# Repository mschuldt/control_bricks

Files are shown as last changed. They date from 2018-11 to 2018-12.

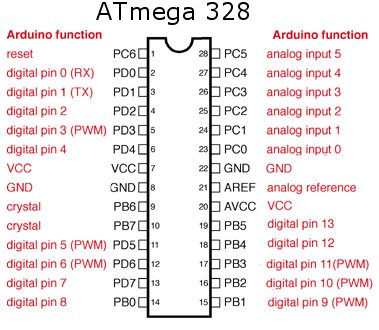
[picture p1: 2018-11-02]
datasheets/atmega328-arduino-pinout.jpg

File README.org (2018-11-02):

Control Bricks

A collection of composable PCBs for building simple automation solutions.

Bricks are connected in sequence, each performing a simple function before
passing control to the next brick. 
Bricks can have inputs for sensors and outputs for actuators.

The goal is to create reliable and maintainable solutions 
without any custom application specific software. 
The PCBs provide buttons and indicators for the control interface. 
Each output has buttons for manual activation for testing and debugging.

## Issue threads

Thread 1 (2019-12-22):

SN74LV8153 is unused

Ryder17z, 2019-12-22:
You have the PDF but the device hasn't been implemented. That's unfortunate.

mschuldt, 2019-12-22:
yup, ended up not needing it. Why is that unfortunate?

Ryder17z, 2019-12-26:
Because I got a bunch of these chips and I want ideas for what to do with them and how.

mschuldt, 2019-12-26:
This project won't help you much in that case

Ryder17z, 2019-12-26:
not with that particular chip, no but otherwise it looks interesting.

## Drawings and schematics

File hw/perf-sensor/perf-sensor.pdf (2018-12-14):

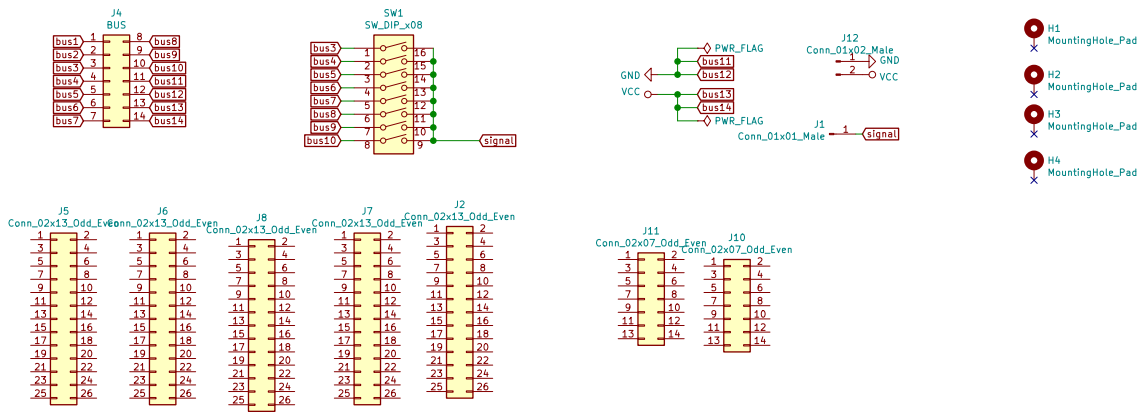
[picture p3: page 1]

File: perf-sensor.sch Sheet: /
Id: 1/1 Title:

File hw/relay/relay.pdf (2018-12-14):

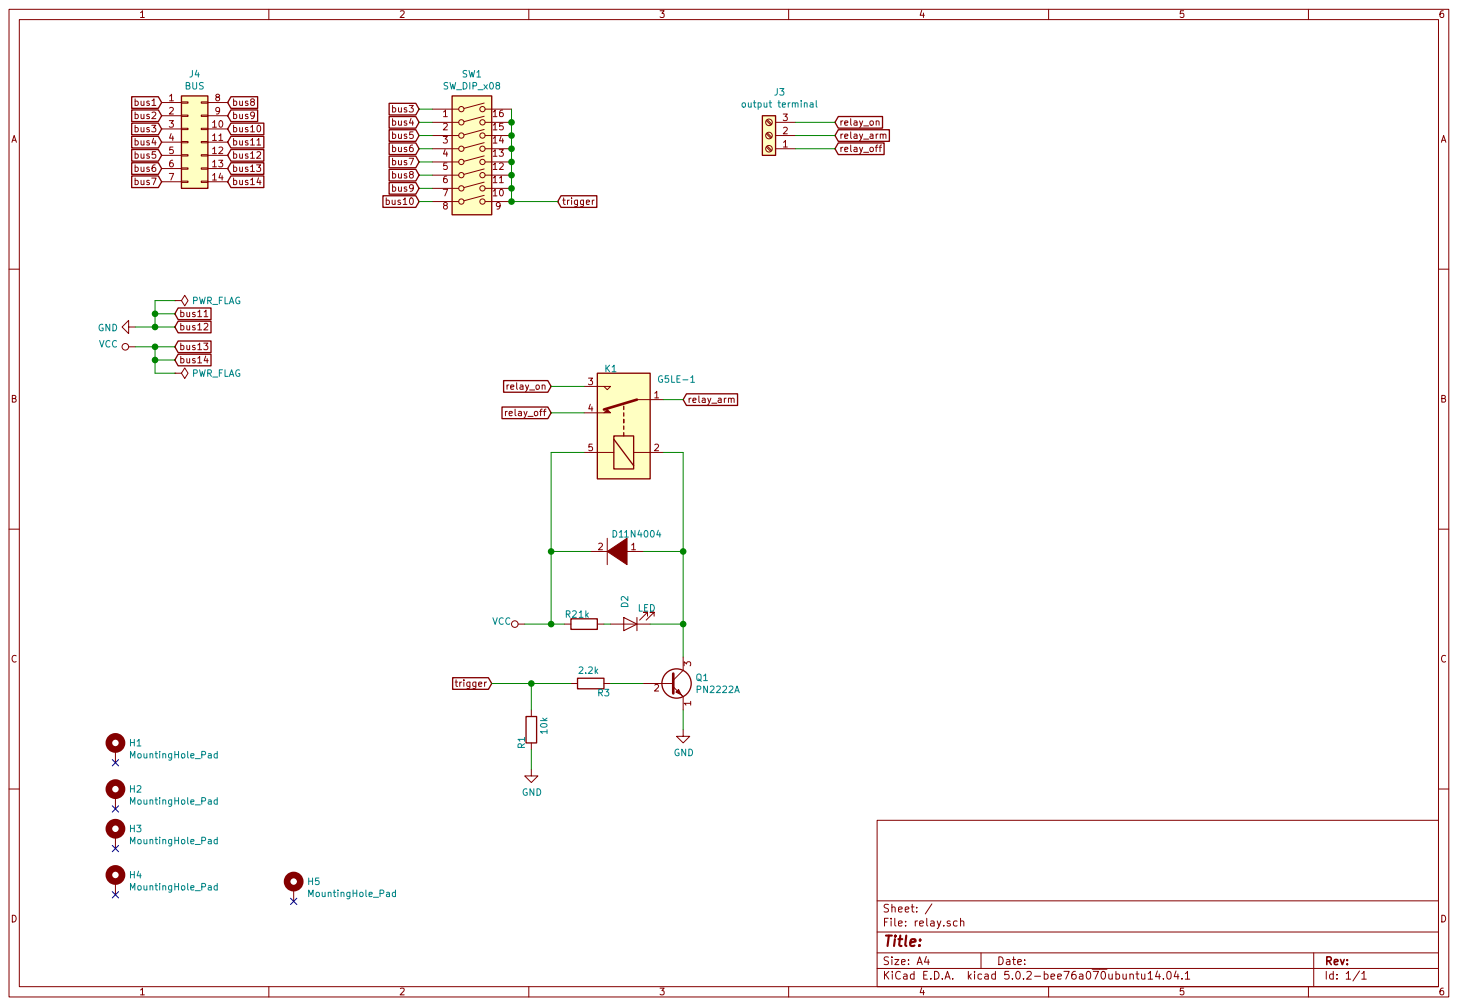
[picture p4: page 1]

File: relay.sch Sheet: /
Id: 1/1 Title:

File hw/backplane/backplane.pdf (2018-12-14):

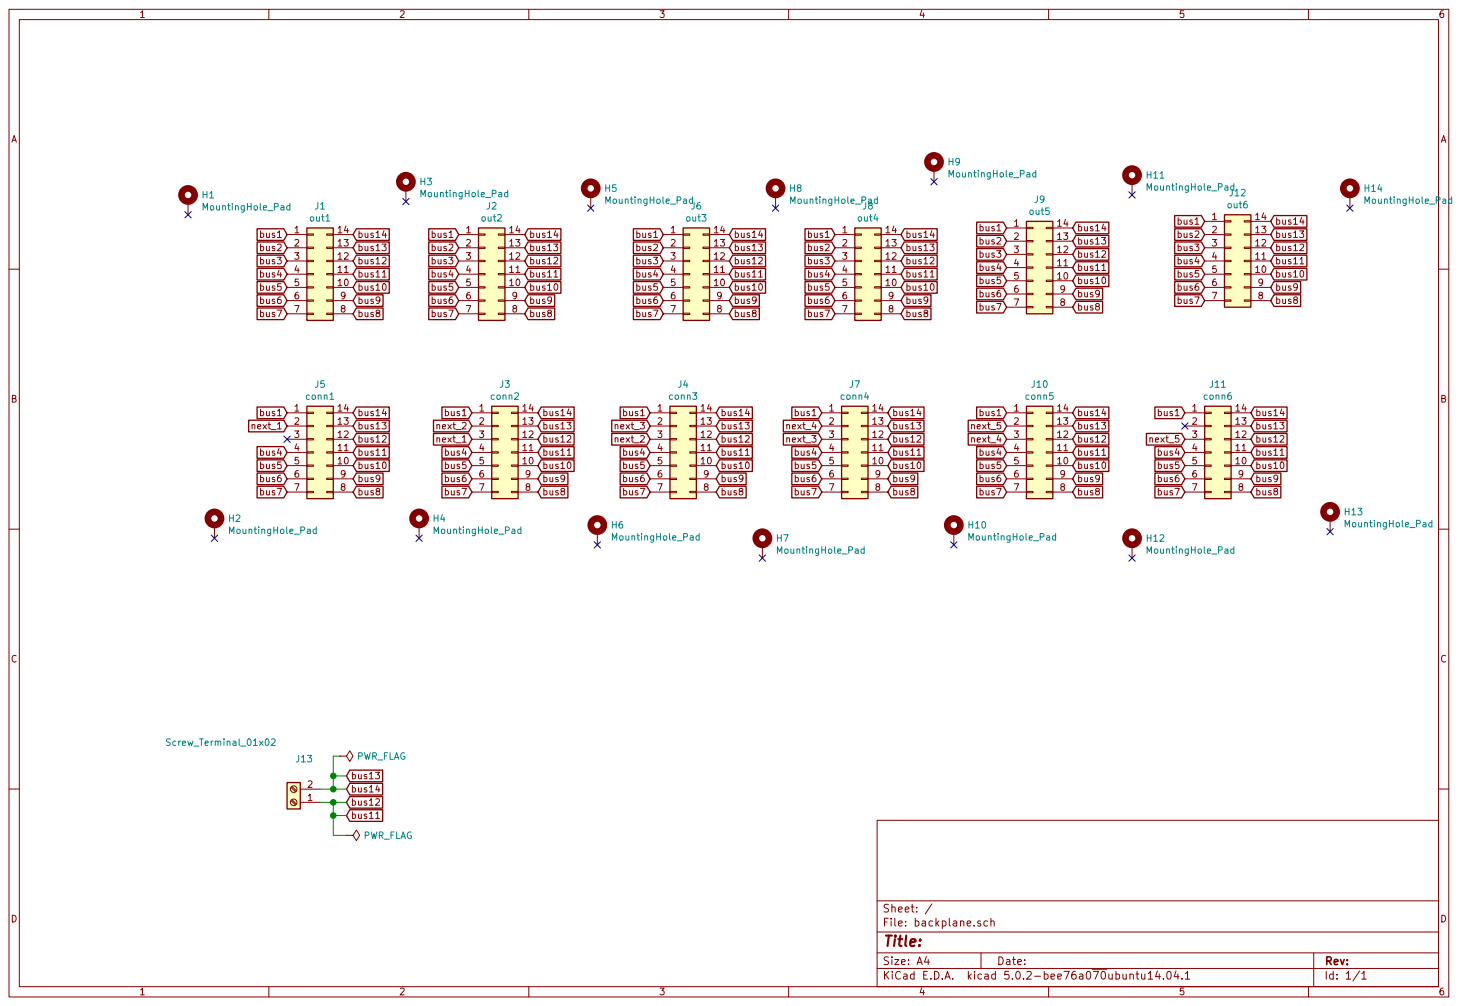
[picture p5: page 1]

File: backplane.sch Sheet: /
Id: 1/1 Title:

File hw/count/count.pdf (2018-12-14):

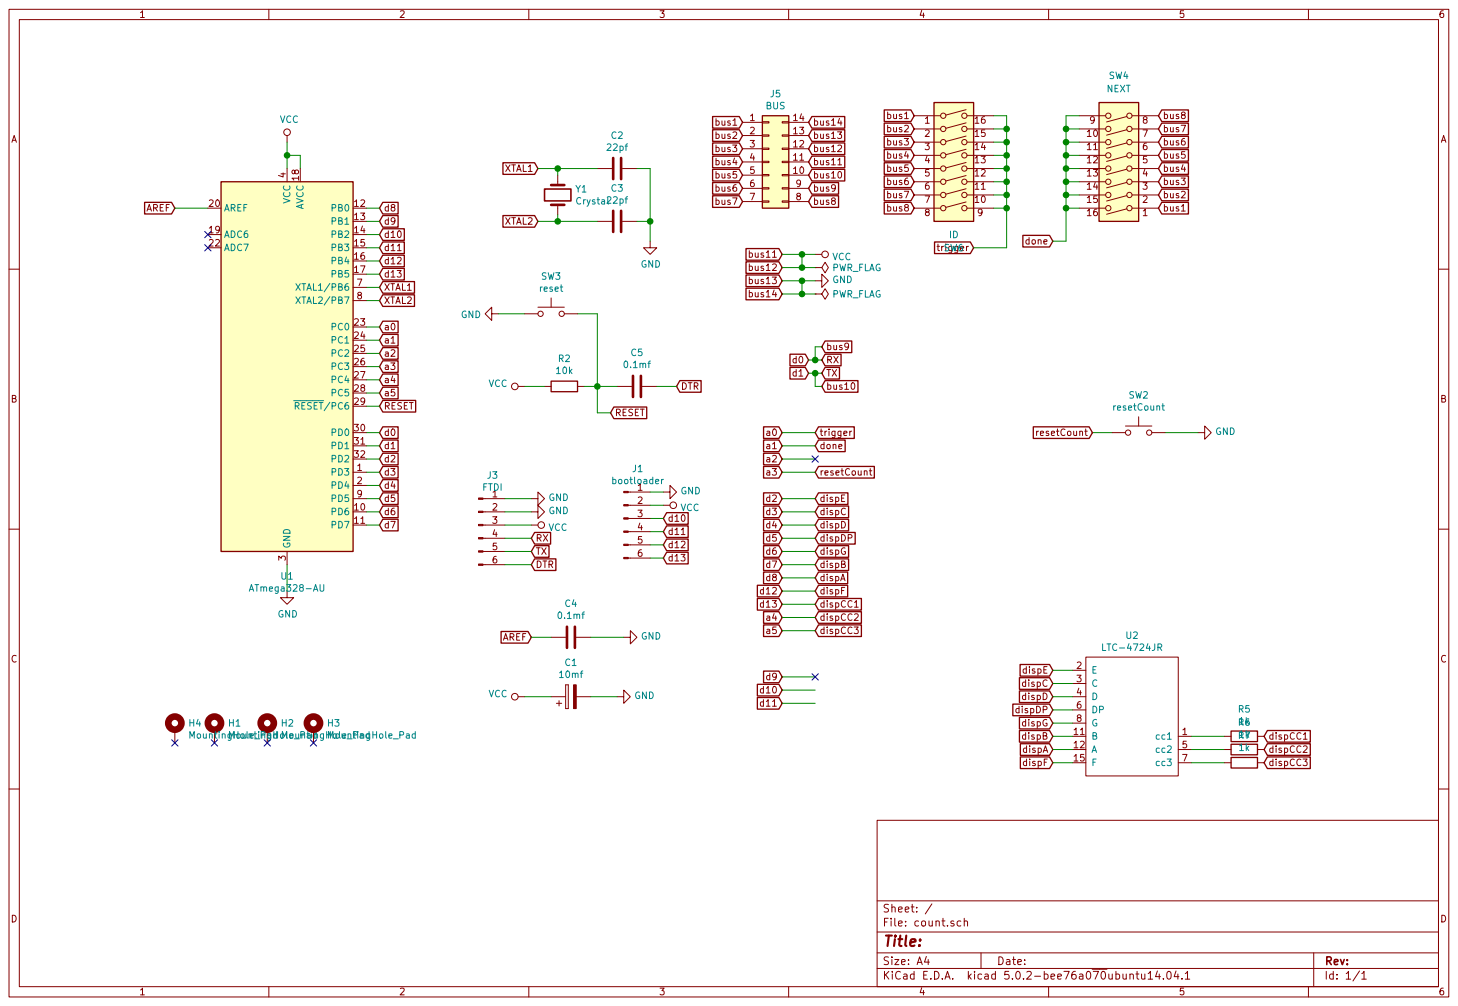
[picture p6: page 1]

Id: 1/1 Title: File: count.sch Sheet: /

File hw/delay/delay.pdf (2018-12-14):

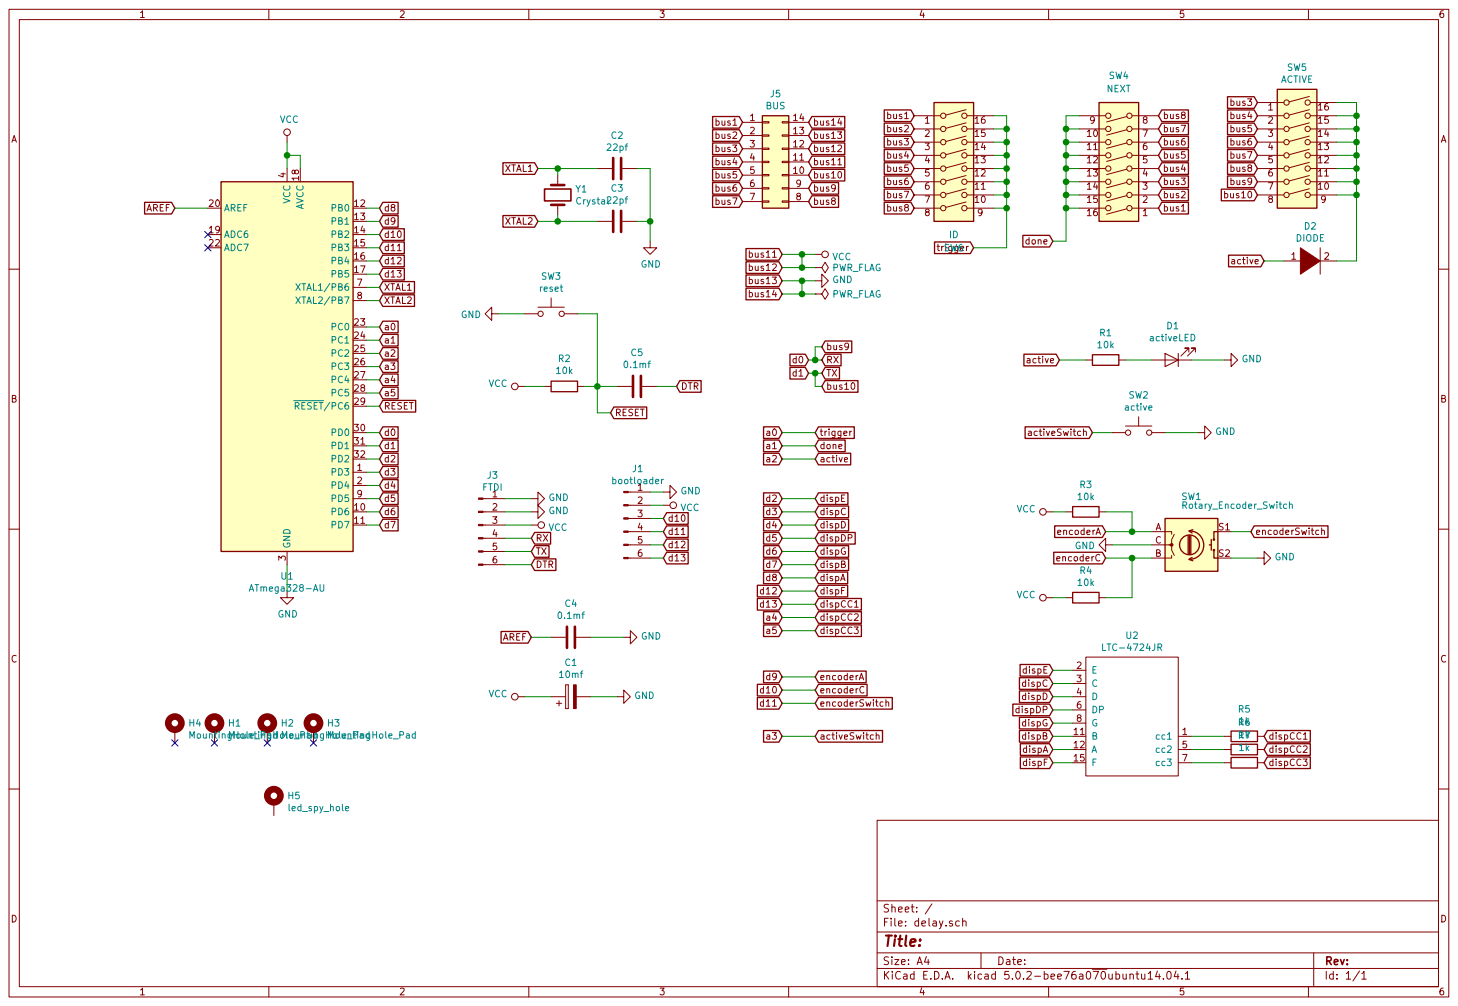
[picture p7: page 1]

File: delay.sch Sheet: /
Id: 1/1 Title:

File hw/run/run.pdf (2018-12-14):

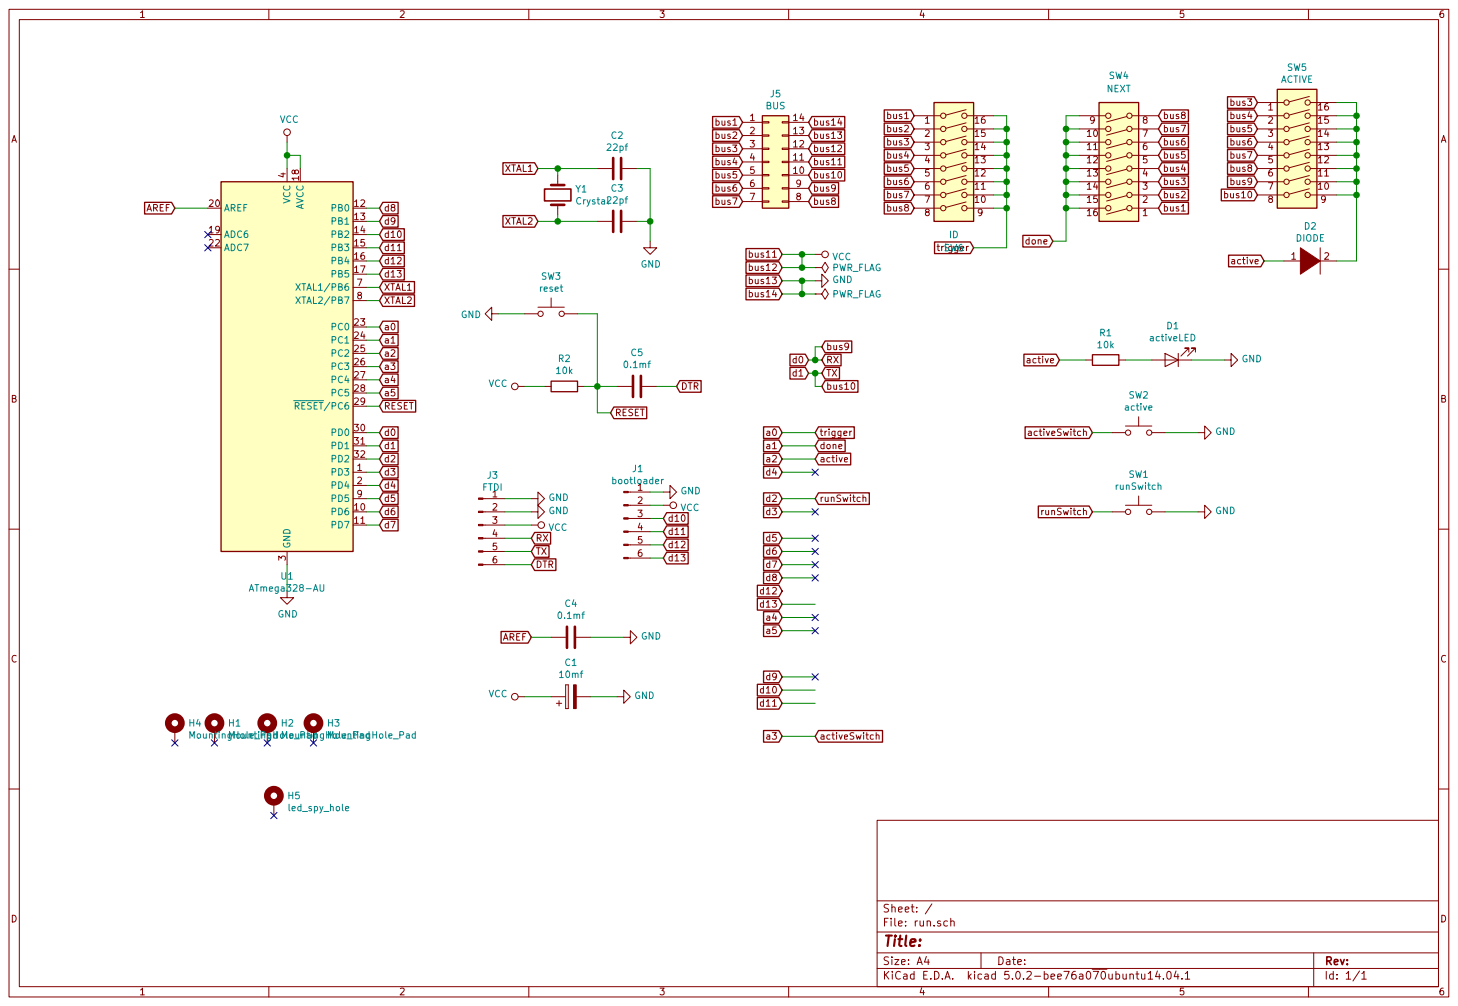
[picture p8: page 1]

Id: 1/1 Title: File: run.sch Sheet: /

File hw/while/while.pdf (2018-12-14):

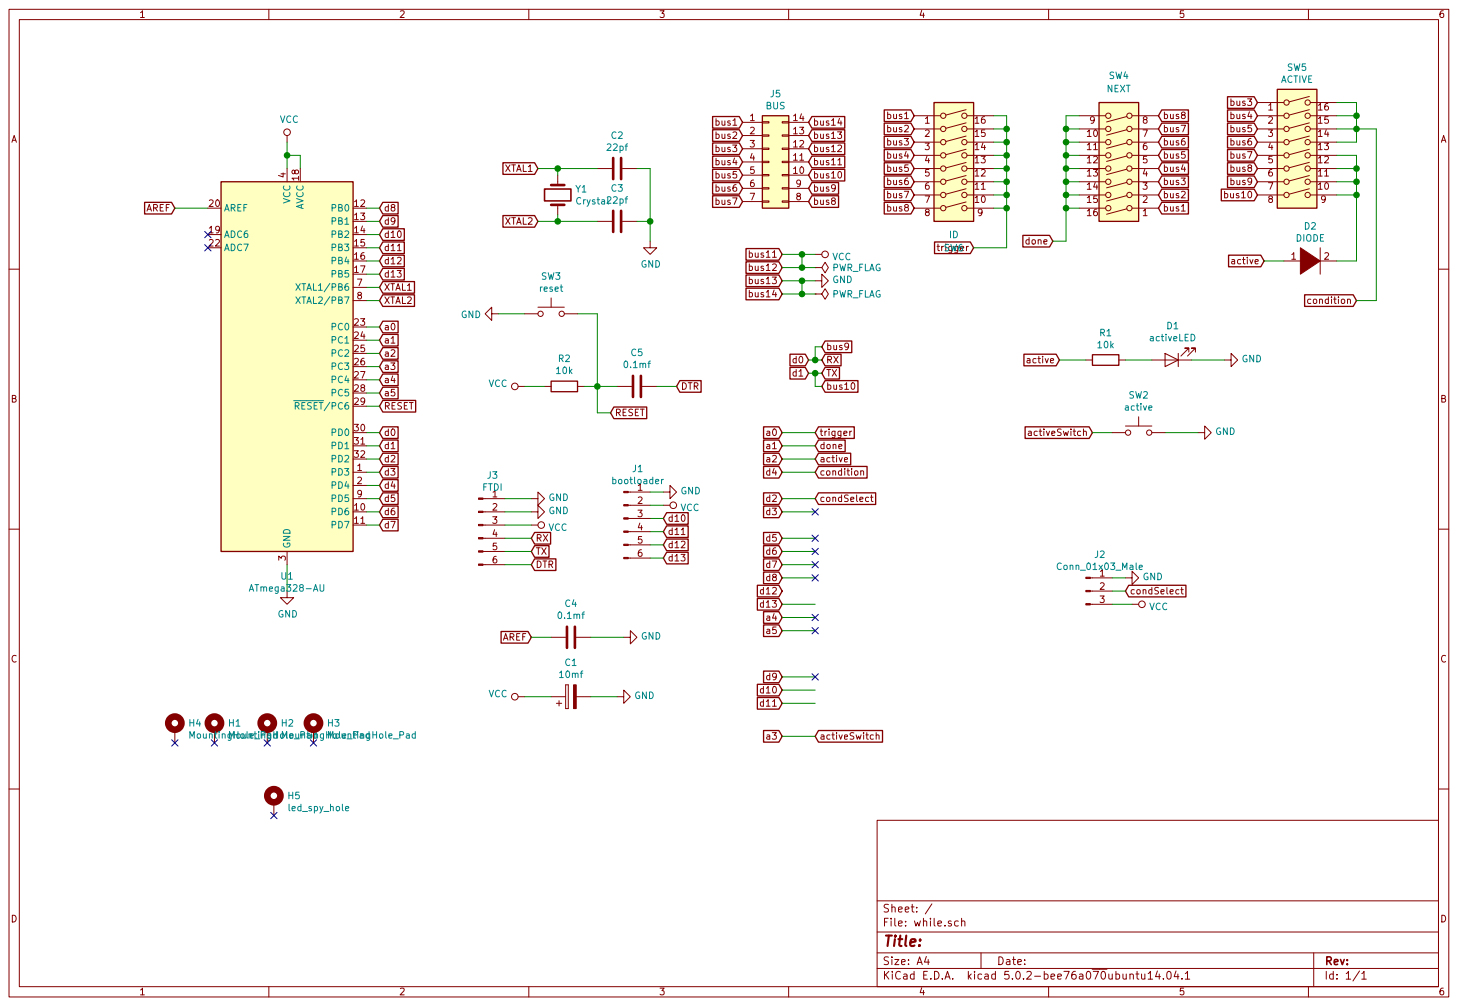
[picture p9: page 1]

Id: 1/1 Title: File: while.sch Sheet: /

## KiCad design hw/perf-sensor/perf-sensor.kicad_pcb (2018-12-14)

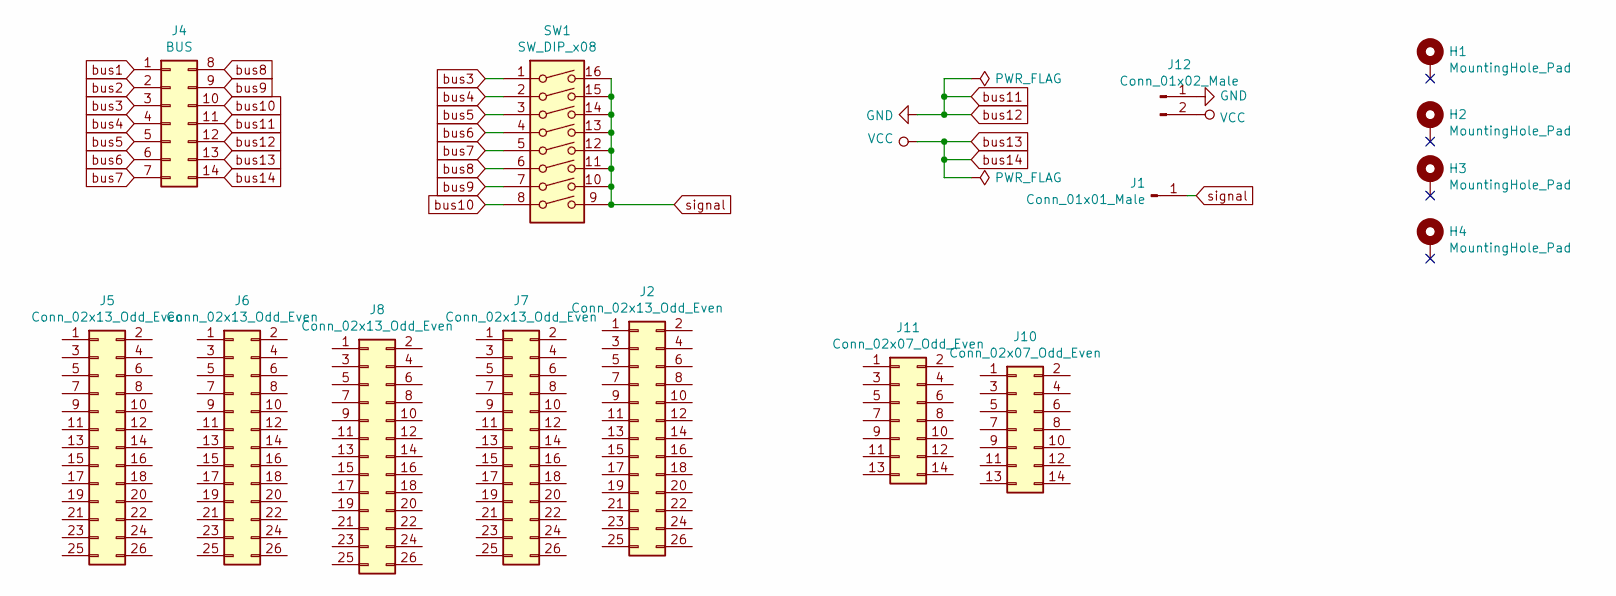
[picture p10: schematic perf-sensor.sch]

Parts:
H1, H2, H3, H4: MountingHole_Pad; MountingHole_3.2mm_M3
J1: Conn_01x01_Male; PinHeader_1x01_P2.54mm_Vertical
J2, J5, J6, J7, J8: Conn_02x13_Odd_Even; PinHeader_2x13_P2.54mm_Vertical
J4: BUS; PinHeader_2x07_P2.54mm_Vertical
J10, J11: Conn_02x07_Odd_Even; PinHeader_2x07_P2.54mm_Vertical
J12: Conn_01x02_Male; PinHeader_1x02_P2.54mm_Vertical
SW1: SW_DIP_x08; DIP-16_W7.62mm_SMDSocket_SmallPads

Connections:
bus1: J4.1
bus2: J4.2
bus3: J4.3, SW1.1
bus4: J4.4, SW1.2
bus5: J4.5, SW1.3
bus6: J4.6, SW1.4
bus7: J4.7, SW1.5
bus8: J4.8, SW1.6
bus9: J4.9, SW1.7
bus10: J4.10, SW1.8
bus11: J4.11, J4.12, J12.1
bus13: J4.13, J4.14, J12.2
signal: J1.1, SW1.9, SW1.10, SW1.11, SW1.12, SW1.13, SW1.14, SW1.15, SW1.16

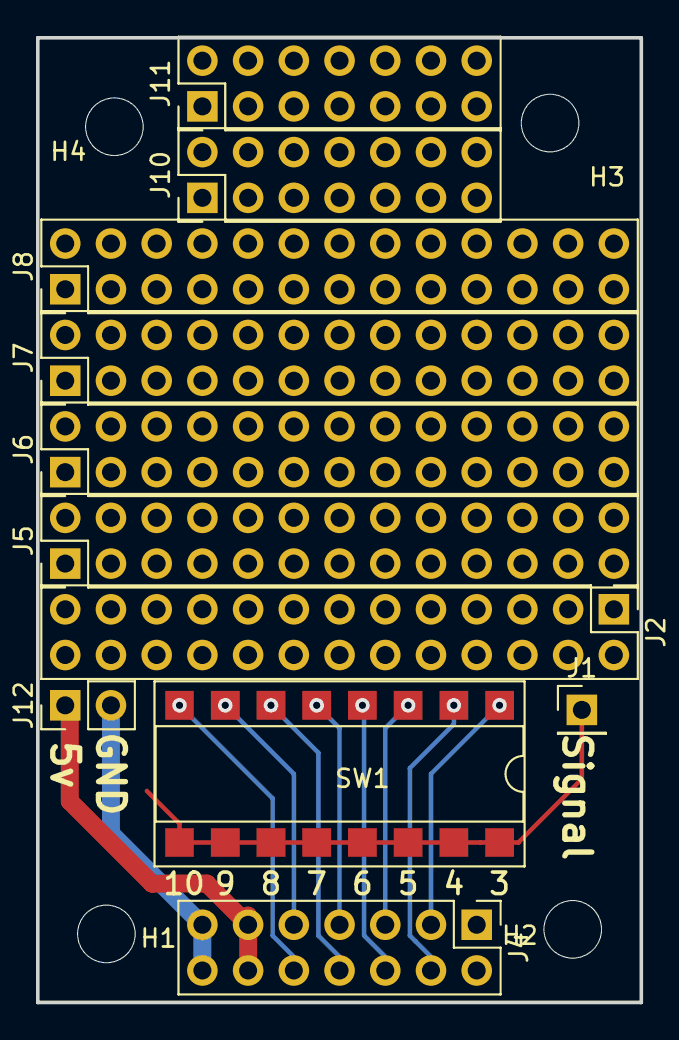
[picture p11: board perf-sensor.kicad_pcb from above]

Board: 2 copper layers, 33.5 x 53.6 mm, 15 parts (0 on the bottom side), 11 nets.

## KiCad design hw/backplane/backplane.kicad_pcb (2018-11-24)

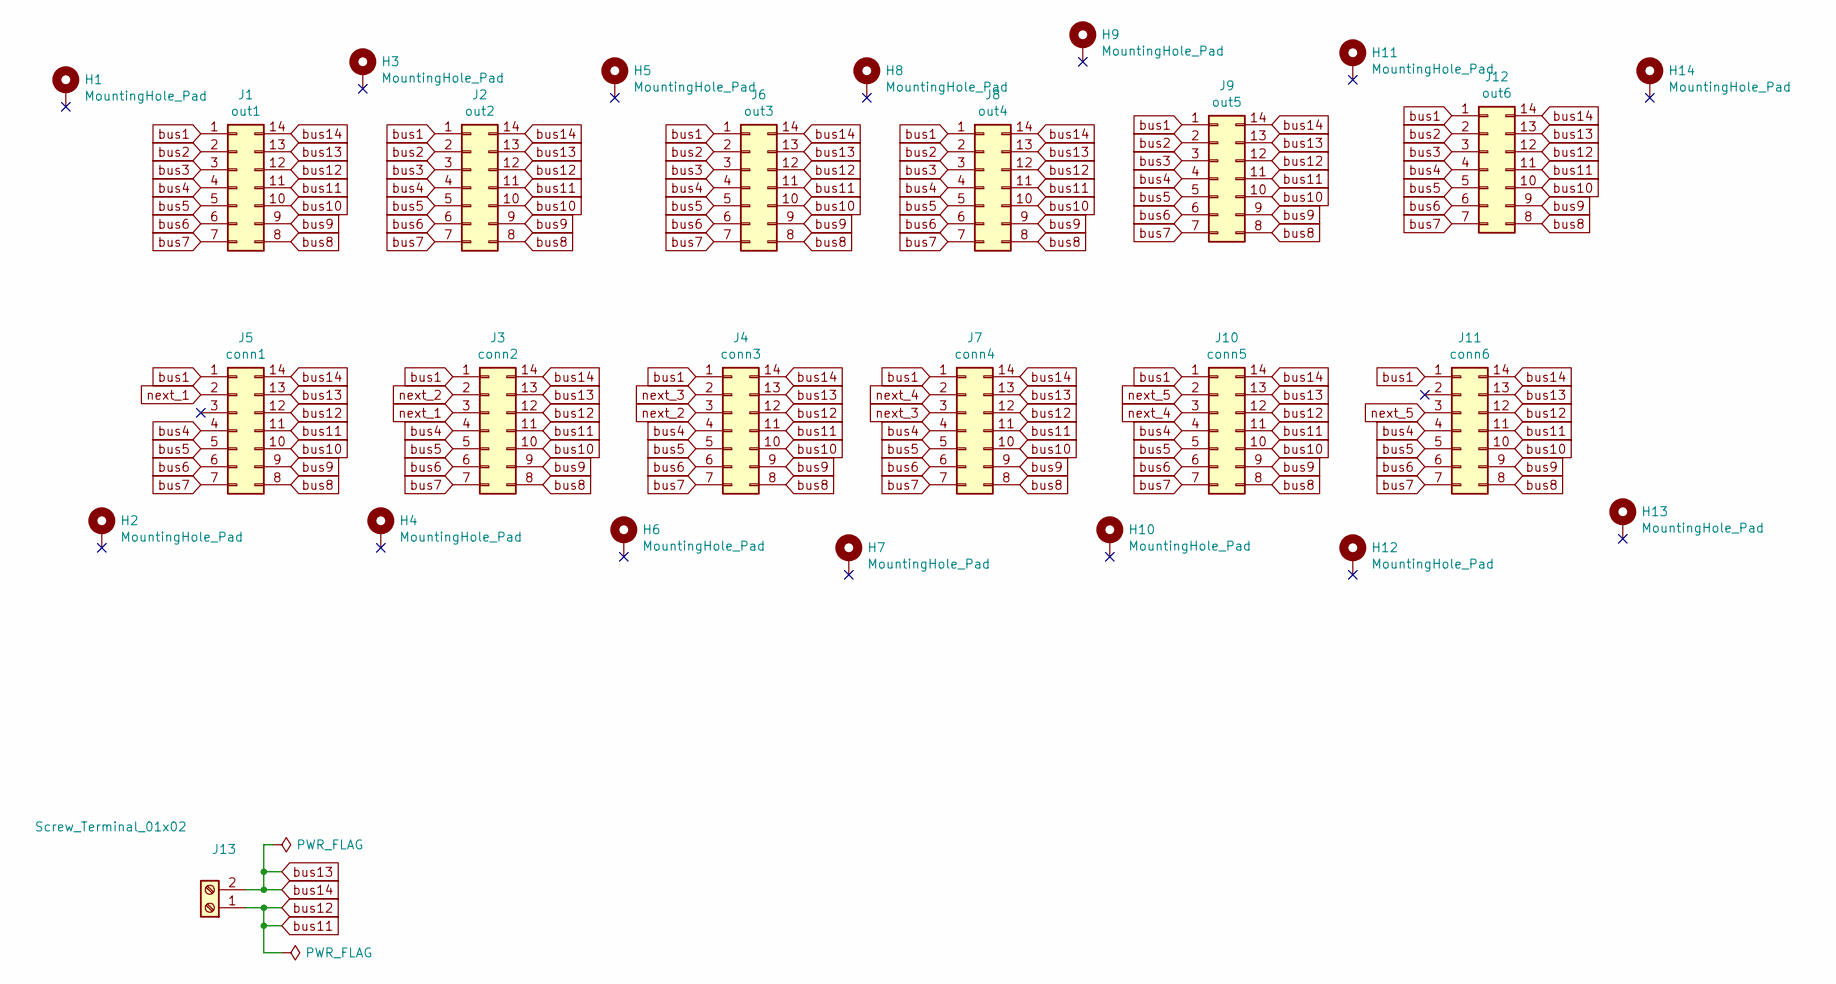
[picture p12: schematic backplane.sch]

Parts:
H1, H2, H3, H4, H5, H6, H7, H8, H9, H10, H11, H12, H13, H14: MountingHole_Pad; MountingHole_3.2mm_M3_Pad
J1: out1; PinHeader_2x07_P2.54mm_Vertical
J2: out2; PinHeader_2x07_P2.54mm_Vertical
J3: conn2; PinHeader_2x07_P2.54mm_Vertical
J4: conn3; PinHeader_2x07_P2.54mm_Vertical
J5: conn1; PinHeader_2x07_P2.54mm_Vertical
J6: out3; PinHeader_2x07_P2.54mm_Vertical
J7: conn4; PinHeader_2x07_P2.54mm_Vertical
J8: out4; PinHeader_2x07_P2.54mm_Vertical
J9: out5; PinHeader_2x07_P2.54mm_Vertical
J10: conn5; PinHeader_2x07_P2.54mm_Vertical
J11: conn6; PinHeader_2x07_P2.54mm_Vertical
J12: out6; PinHeader_2x07_P2.54mm_Vertical
J13: Screw_Terminal_01x02; PinHeader_1x02_P2.54mm_Vertical

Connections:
bus1: J1.1, J2.1, J3.1, J4.1, J5.1, J6.1, J7.1, J8.1, J9.1, J10.1, J11.1, J12.1
bus2: J1.2, J2.2, J6.2, J8.2, J9.2, J12.2
bus3: J1.3, J2.3, J6.3, J8.3, J9.3, J12.3
bus4: J1.4, J2.4, J3.4, J4.4, J5.4, J6.4, J7.4, J8.4, J9.4, J10.4, J11.4, J12.4
bus5: J1.5, J2.5, J3.5, J4.5, J5.5, J6.5, J7.5, J8.5, J9.5, J10.5, J11.5, J12.5
bus6: J1.6, J2.6, J3.6, J4.6, J5.6, J6.6, J7.6, J8.6, J9.6, J10.6, J11.6, J12.6
bus7: J1.7, J2.7, J3.7, J4.7, J5.7, J6.7, J7.7, J8.7, J9.7, J10.7, J11.7, J12.7
bus8: J1.8, J2.8, J3.8, J4.8, J5.8, J6.8, J7.8, J8.8, J9.8, J10.8, J11.8, J12.8
bus9: J1.9, J2.9, J3.9, J4.9, J5.9, J6.9, J7.9, J8.9, J9.9, J10.9, J11.9, J12.9
bus10: J1.10, J2.10, J3.10, J4.10, J5.10, J6.10, J7.10, J8.10, J9.10, J10.10, J11.10, J12.10
bus11: J1.11, J1.12, J2.11, J2.12, J3.11, J3.12, J4.11, J4.12, J5.11, J5.12, J6.11, J6.12, J7.11, J7.12, J8.11, J8.12, J9.11, J9.12, J10.11, J10.12, J11.11, J11.12, J12.11, J12.12, J13.1
bus13: J1.13, J1.14, J2.13, J2.14, J3.13, J3.14, J4.13, J4.14, J5.13, J5.14, J6.13, J6.14, J7.13, J7.14, J8.13, J8.14, J9.13, J9.14, J10.13, J10.14, J11.13, J11.14, J12.13, J12.14, J13.2
next_1: J3.3, J5.2
next_2: J3.2, J4.3
next_3: J4.2, J7.3
next_4: J7.2, J10.3
next_5: J10.2, J11.3

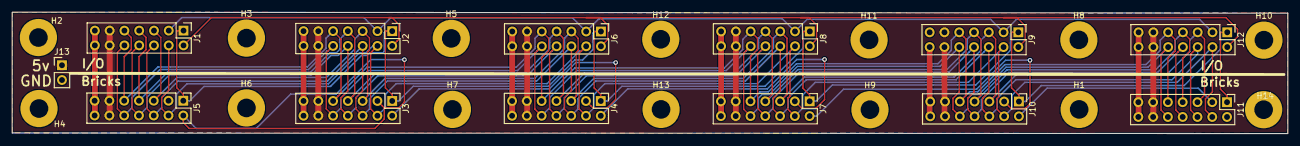
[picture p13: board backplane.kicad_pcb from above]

Board: 2 copper layers, 219.2 x 20.9 mm, 27 parts (0 on the bottom side), 17 nets.

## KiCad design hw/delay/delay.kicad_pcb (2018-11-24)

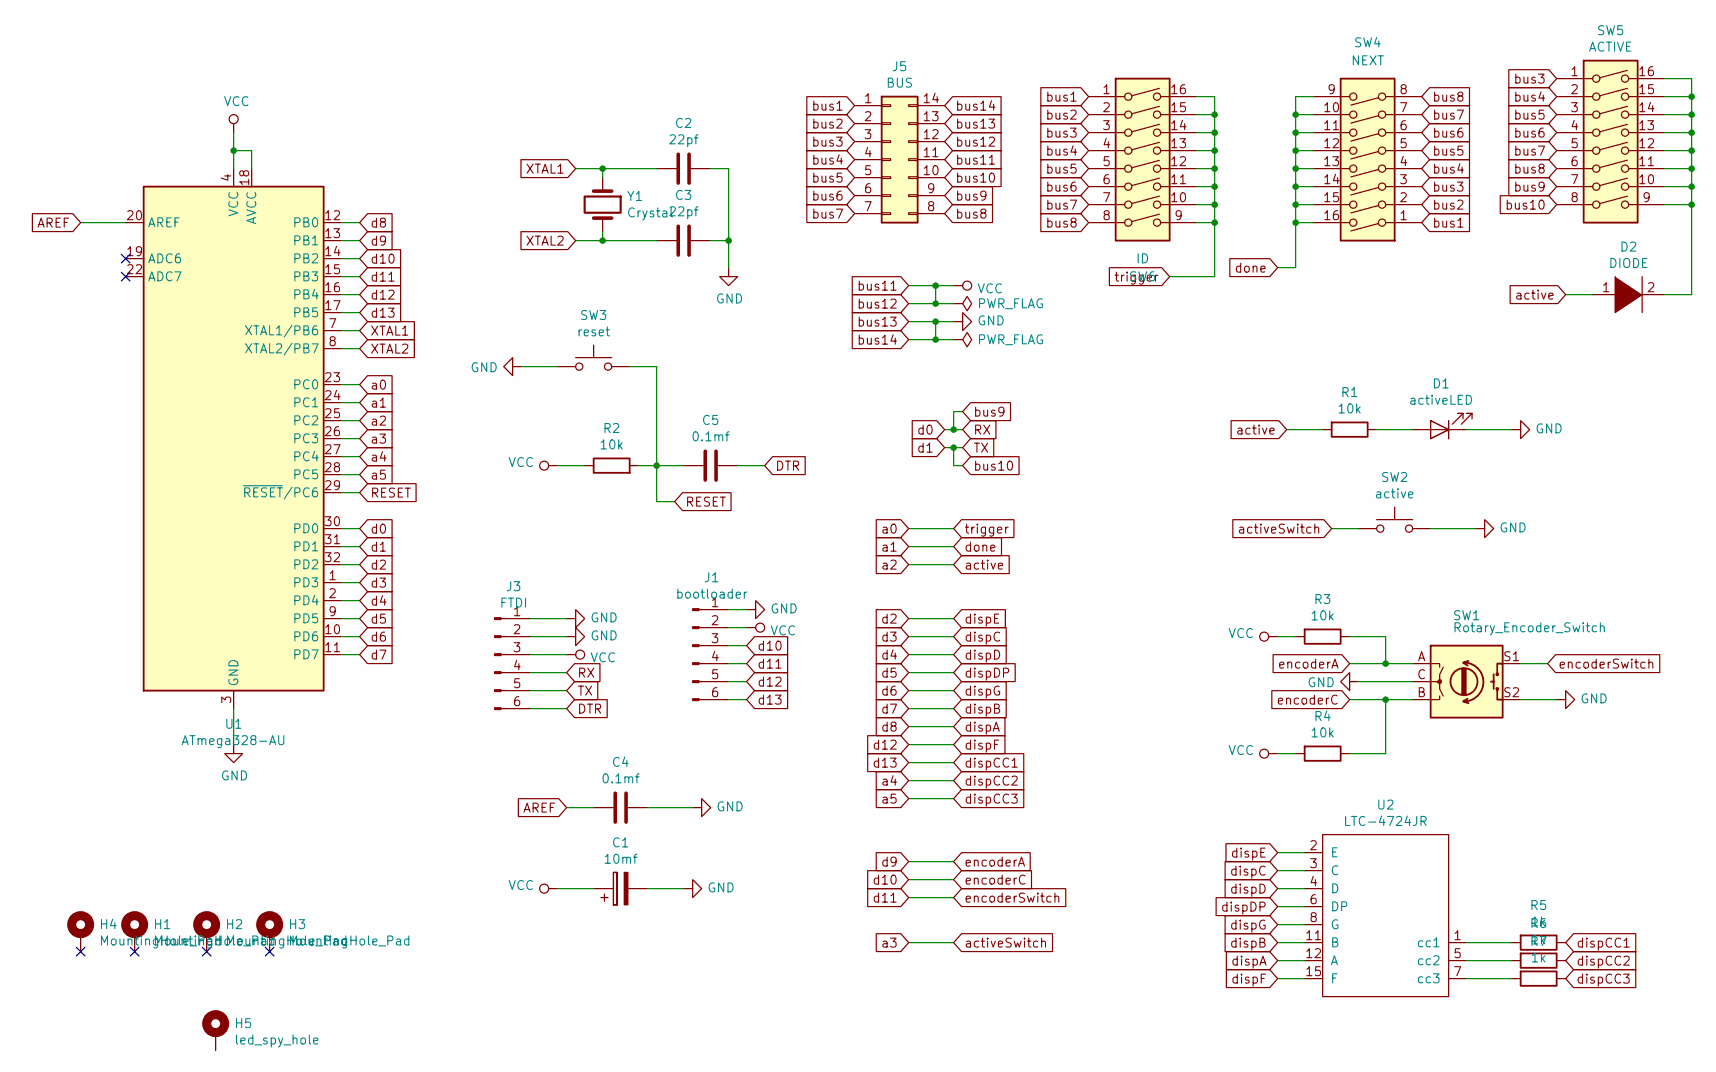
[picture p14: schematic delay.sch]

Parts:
C1: 10mf; C_0603_1608Metric
C2, C3: 22pf; C_0603_1608Metric
C4, C5: 0.1mf; C_0603_1608Metric
D1: activeLED; LED_D5.0mm
D2: DIODE; D_0603_1608Metric
H1, H2, H3, H4: MountingHole_Pad; MountingHole_3.2mm_M3_Pad
H5: led_spy_hole; MountingHole_3.2mm_M3
J1: bootloader; edge_connector_3
J3: FTDI; edge_connector_3
J5: BUS; PinHeader_2x07_P2.54mm_Vertical
R1, R2, R3, R4: 10k; R_0603_1608Metric
R5, R6, R7: 1k; R_0603_1608Metric
SW1: Rotary_Encoder_Switch; RotaryEncoder_Alps_EC11E-Switch_Vertical_H20mm_CircularMoun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
SW2: active; SW_SPST_TL3305C
SW3: reset; SW_SPST_TL3305C
SW4: NEXT; DIP-16_W7.62mm_SMDSocket_SmallPads
SW5: ACTIVE; DIP-16_W7.62mm_SMDSocket_SmallPads
SW6: ID; DIP-16_W7.62mm_SMDSocket_SmallPads
U1: ATmega328-AU; TQFP-32_7x7mm_P0.8mm
U2: LTC-4724JR
Y1: Crystal; Crystal_SMD_HC49-SD

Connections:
AREF: C4.1, U1.20 (AREF)
DTR: C5.2, J3.6
unnamed: D1.2 (A), R1.1
unnamed: D2.2 (A), SW5.9, SW5.10, SW5.11, SW5.12, SW5.13, SW5.14, SW5.15, SW5.16
unnamed: R5.2, U2.1 (cc1)
unnamed: R6.2, U2.5 (cc2)
unnamed: R7.2, U2.7 (cc3)
RESET: C5.1, R2.2, SW3.2, U1.29 (~RESET~/PC6)
RX: J3.4, J5.9, SW5.7, U1.30 (PD0)
TX: J3.5, J5.10, SW5.8, U1.31 (PD1)
XTAL1: C2.2, U1.7 (XTAL1/PB6), Y1.1
XTAL2: C3.2, U1.8 (XTAL2/PB7), Y1.2
a0: SW6.9, SW6.10, SW6.11, SW6.12, SW6.13, SW6.14, SW6.15, SW6.16, U1.23 (PC0)
a1: SW4.9, SW4.10, SW4.11, SW4.12, SW4.13, SW4.14, SW4.15, SW4.16, U1.24 (PC1)
a2: D2.1 (K), R1.2, U1.25 (PC2)
a3: SW2.1, U1.26 (PC3)
a4: R6.1, U1.27 (PC4)
a5: R7.1, U1.28 (PC5)
bus1: J5.1, SW4.1, SW6.1
bus2: J5.2, SW4.2, SW6.2
bus3: J5.3, SW4.3, SW5.1, SW6.3
bus4: J5.4, SW4.4, SW5.2, SW6.4
bus5: J5.5, SW4.5, SW5.3, SW6.5
bus6: J5.6, SW4.6, SW5.4, SW6.6
bus7: J5.7, SW4.7, SW5.5, SW6.7
bus8: J5.8, SW4.8, SW5.6, SW6.8
bus11: C1.1, J1.2, J3.3, J5.11, J5.12, R2.1, R3.2, R4.2, U1.4 (VCC), U1.6 (VCC), U1.18 (AVCC)
bus13: C1.2, C2.1, C3.1, C4.2, D1.1 (K), J1.1, J3.1, J3.2, J5.13, J5.14, SW1.C, SW1.S2, SW2.2, SW3.1, U1.3 (GND), U1.5 (GND), U1.21 (GND)
d2: U1.32 (PD2), U2.2 (E)
d3: U1.1 (PD3), U2.3 (C)
d4: U1.2 (PD4), U2.4 (D)
d5: U1.9 (PD5), U2.6 (DP)
d6: U1.10 (PD6), U2.8 (G)
d7: U1.11 (PD7), U2.11 (B)
d8: U1.12 (PB0), U2.12 (A)
d9: R3.1, SW1.A, U1.13 (PB1)
d10: J1.3, R4.1, SW1.B, U1.14 (PB2)
d11: J1.4, SW1.S1, U1.15 (PB3)
d12: J1.5, U1.16 (PB4), U2.15 (F)
d13: J1.6, R5.1, U1.17 (PB5)

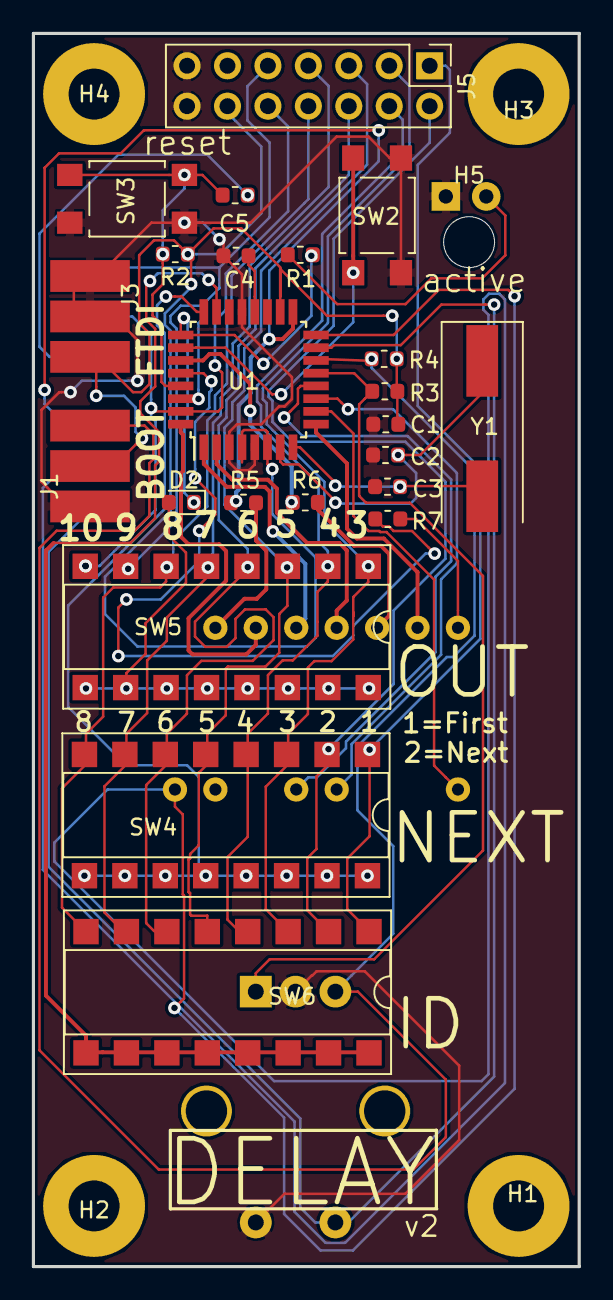
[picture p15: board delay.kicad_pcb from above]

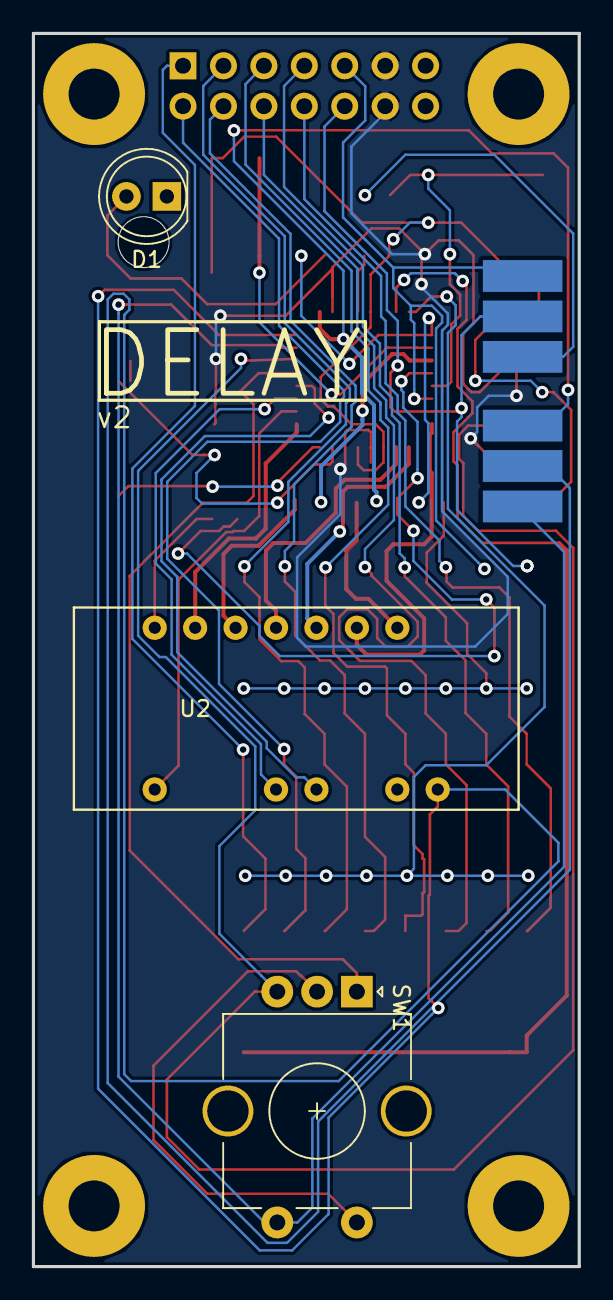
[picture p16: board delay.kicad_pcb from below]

Board: 2 copper layers, 34.3 x 77.5 mm, 31 parts (3 on the bottom side), 40 nets.

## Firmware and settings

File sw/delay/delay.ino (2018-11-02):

// 10k pullup resistors on encoder pins A and B, C to GND

#define PULSE_LEN 100
#define DEFAULT_DELAY 2

#define trigger_pin A0
#define done_pin A1
#define active_pin A2
#define active_button_pin A3

#define encoderPinA 9
#define encoderPinB 10
#define resetButtonPin 11

int encoderPos = 0;
bool encoderPinALast = LOW;

bool force_on = false;
bool active = false;
bool active_pin_state = false;
unsigned int last_press;

void update_active(){
  bool state = active || force_on;
  if (active_pin_state != state){
    digitalWrite(active_pin, state);
    active_pin_state = state;
  }
}

void delay_s(unsigned int s){
  for(;s>0; s--){
    display_num(s);
    update_active();
    delay_ms(1000);
  }
}

void done(){
  active = false;
  digitalWrite(done_pin, LOW);
  delay_ms(PULSE_LEN);
  digitalWrite(done_pin, HIGH);
}

void do_encoder(){
  bool val = digitalRead(encoderPinA);
  if ((encoderPinALast == LOW) && (val == HIGH)) {
    encoderPos += digitalRead(encoderPinB) == LOW ? -1 : 1;
  }
  encoderPinALast = val;
  if (encoderPos < 0){
    encoderPos = 0;
  }
}

void handle_reset_button(){
  if (digitalRead(resetButtonPin) == LOW){ // button bounce is ok here
    encoderPos = 0;
  }
}

void do_delay(){
  if (encoderPos > 0){
    active = true;
    delay_s(encoderPos);
  }
  done();
}

void handle_trigger(){
  if (digitalRead(trigger_pin) == LOW){
    do_delay();
  }
}

void handle_active_button(){
  if (millis() - last_press < 100){
    return;
  }
  last_press = millis();
  force_on = digitalRead(active_button_pin)==LOW;
}

void setup() {
  pinMode(encoderPinA, INPUT);
  pinMode(encoderPinB, INPUT);
  pinMode(resetButtonPin, INPUT_PULLUP);
  pinMode(trigger_pin, INPUT_PULLUP);
  pinMode(done_pin, OUTPUT);
  pinMode(active_pin, OUTPUT);
  digitalWrite(active_pin, LOW);
  pinMode(active_button_pin, INPUT_PULLUP);
  digitalWrite(done_pin, HIGH);

  display_init();
  display_brightness(100);
  last_press = millis();
  do_encoder();
  encoderPos = DEFAULT_DELAY;
  display_num(888);
  delay_ms(1000);
}

void loop() {
  do_encoder();
  handle_reset_button();
  handle_trigger();
  handle_active_button();
  update_active();
  display_num(encoderPos);
  // NOTE: delays here cause errors with the encoder.
}

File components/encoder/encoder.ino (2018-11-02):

// 10k pullup resistors on encoder pins A and B, C to GND

int val = LOW;
int encoderPinA = 3;
int encoderPinB = 4;
int encoderPos = 1;
int encoderPinALast = LOW;
int resetButtonPin = 5;

void doEncoder(){
  val = digitalRead(encoderPinA);
  if ((encoderPinALast == LOW) && (val == HIGH)) {
    if (digitalRead(encoderPinB) == LOW) {
      encoderPos--;
    } else {
      encoderPos++;
    }
  }
  Serial.println(encoderPos);  
  encoderPinALast = val;
}

void doResetButton(){
}

void setup() {
  pinMode(encoderPinA, INPUT);
  pinMode(encoderPinB, INPUT);
  pinMode(resetButtonPin, INPUT);
  pinMode(13, OUTPUT);
 Serial.begin(9600);
}

void loop() {
  doEncoder();
  doResetButton();
}

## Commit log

2018-11-02 update hardware
    [count.kicad_pcb, count.sch, delay.kicad_pcb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]
2018-11-21 DELAY block v2
    [delay-B.Cu.gbl, delay-B.Mask.gbs, delay-B.Paste.gbp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]
2018-11-21 WHILE block v2
    [while-B.Cu.gbl, while-B.Mask.gbs, while-B.Paste.gbp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]
2018-11-21 COUNT block v2
    [count-B.Cu.gbl, count-B.Mask.gbs, count-B.Paste.gbp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]
2018-11-21 RUN block v2
    [run-B.Cu.gbl, run-B.Mask.gbs, run-B.Paste.gbp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]
2018-11-23 update backplane
    [backplane-B.Cu.gbl, backplane-B.Mask.gbs, backplane-B.Paste.gbp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]
2018-11-23 fix DELAY bus assigments
    [delay-B.Cu.gbl, delay-B.Mask.gbs, delay-B.Paste.gbp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]
2018-11-23 fix WHILE bus assignemnts
    [while-B.Cu.gbl, while-B.Mask.gbs, while-B.Paste.gbp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]
2018-11-23 fix COUNT bus assigments
    [count-B.Cu.gbl, count-B.Mask.gbs, count-B.Paste.gbp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]
2018-11-23 fix RUN bus assigments
    [run-B.Cu.gbl, run-B.Mask.gbs, run-B.Paste.gbp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]
2018-11-23 RELAY bus connection
    [relay-B.Cu.gbr, relay-B.Mask.gbr, relay-B.Paste.gbr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]
2018-11-24 perf sensor
    [perf-sensor-B.Cu.gbr, perf-sensor-B.Mask.gbr, perf-sensor-B.Paste.gbr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]
2018-12-14 relay layout changes
    [relay-B.Cu.gbl, relay-B.Mask.gbs, relay-B.Paste.gbp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]
2018-12-15 single zip-gerbers script
2018-12-17 update DELAY block files
    [delay-NPTH.drl, delay-PTH.drl, delay.drl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]
